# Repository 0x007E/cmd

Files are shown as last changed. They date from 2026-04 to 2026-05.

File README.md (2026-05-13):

  

# `CMD` - Color Matrix Display

The `CMD` is a board with a matrix of [APA102](#additional-information) or any other `SPI` controllable `RGB-LED`. The board itself can be driven with a voltage from `3V3-5V` and controlled over the [APA102 driver library](https://github.com/0x007E/drivers-led-apa102).

| Experience  | Level |
|:---|:---:|
| Soldering | ?% |

# Downloads

| Type | File | Description |
|:---:|:---:|:---|
| Schematic | [pdf](https://github.com/0x007E/cmd/releases/latest/download/schematic.pdf) / [cadlab](https://cadlab.io/project/30127/main/files) | Schematic files |
| Board | [pdf](https://github.com/0x007E/cmd/releases/latest/download/pcb.pdf) / [cadlab](https://cadlab.io/project/30127/main/files) | Board file |
| Drill | [pdf](https://github.com/0x007E/cmd/releases/latest/download/drill.pdf) | Drill file |
| PCB | [zip](https://github.com/0x007E/cmd/releases/latest/download/kicad.zip) / [tar](https://github.com/0x007E/cmd/releases/latest/download/kicad.tar.gz) | KiCAD/Gerber/BoM/Drill files |
| Mechanical | [zip](https://github.com/0x007E/cmd/releases/latest/download/freecad.zip) / [tar](https://github.com/0x007E/cmd/releases/latest/download/freecad.tar.gz) | FreeCAD/Housing and exported step/stl files |

# Hardware

The pcb is created with `KiCAD`, the housing with `FreeCAD`. All files are built with `github actions` so that they are ready for a production environment.

## PCB

The circuit board is populated on both sides (Top, Bottom). The best way for soldering the `SMD` components is within a vapor phase soldering system and for the `THT` components with a standard soldering system.

### Top Layer

Top Layer

### Bottom Layer

Bottom Layer

## Mechanical

The housing has a tolerance of `0.2mm` on each side of the case. So the pcb should fit perfectly in the housing. The tolerance can be modified with `FreeCAD` in the `Parameter` Spreadsheet.

### Assembled

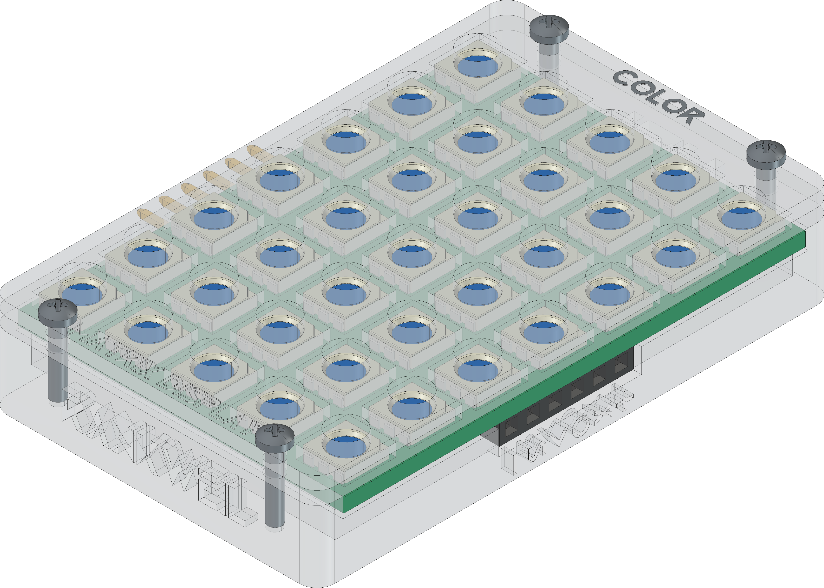
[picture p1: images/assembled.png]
Assembled


### Exploded

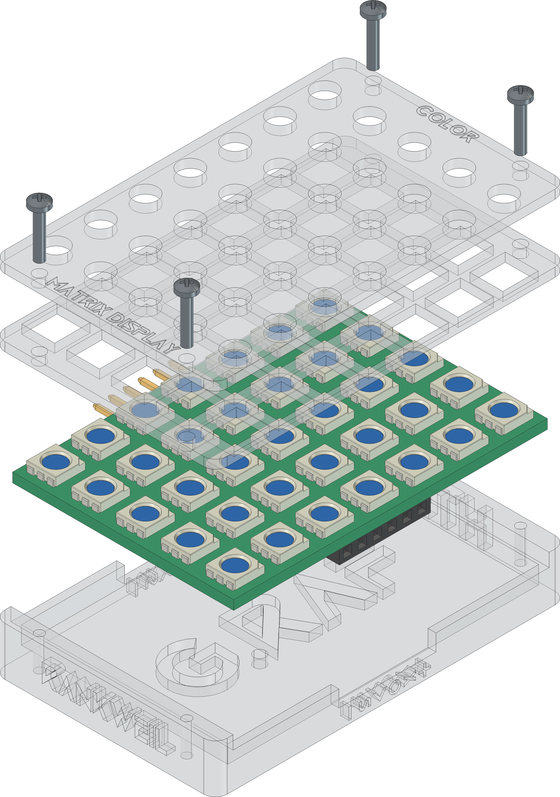
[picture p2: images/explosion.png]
Exploded


# Additional Information

| Type | Link | Description |
|:---:|:---:|:---|
| APA102 | [pdf](https://cdn.sparkfun.com/datasheets/Components/LED/APA102C.pdf) | RGB Full Color LED |
| T3A33BRG | [pdf](https://mm.digikey.com/Volume0/opasdata/d220001/medias/docus/6794/3147_T3A33BRG-H9C0002X1U1930.pdf) | Harvatek Surface Mount PLCC IC+RGB LEDs Data Sheet |

---

R. GAECHTER

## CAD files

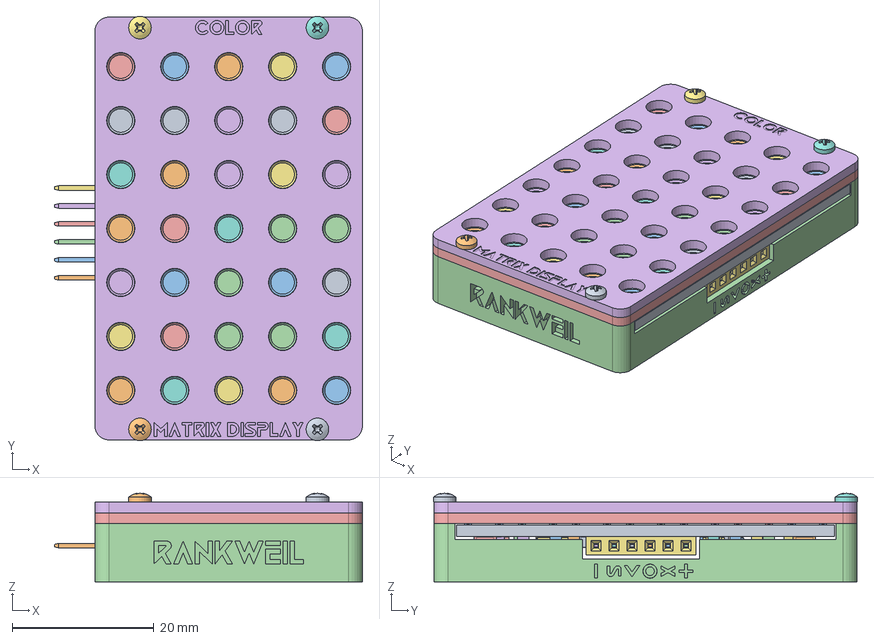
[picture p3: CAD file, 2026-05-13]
mechanical/housing.FCStd
43.5 x 59.9 x 12.5 mm
Pcb_372d
D4_LED_RGB_5050_6_c8d679b3cf96
D12_LED_RGB_5050_6_0d78efd88531
D25_LED_RGB_5050_6_8dd86f10e033
D30_LED_RGB_5050_6_70bff24c3fa8
D5_LED_RGB_5050_6_883a80191dc6
D21_LED_RGB_5050_6_71d8c5f033c3
D18_LED_RGB_5050_6_ae8a0c82b528
D2_LED_RGB_5050_6_2c67bf760a38
D15_LED_RGB_5050_6_4aecfc53b693
D29_LED_RGB_5050_6_020e96eb8e85
D27_LED_RGB_5050_6_e6c08294998b
D13_LED_RGB_5050_6_5207545b7e46
D31_LED_RGB_5050_6_452964f9abc9
D6_LED_RGB_5050_6_48a015607da9
D14_LED_RGB_5050_6_ef4cea893bd8
D33_LED_RGB_5050_6_c87c4f9d566a
D7_LED_RGB_5050_6_5112adf0dffb
D26_LED_RGB_5050_6_b665db2f56eb
D20_LED_RGB_5050_6_2f6135911f3c
D11_LED_RGB_5050_6_c472883db714
D17_LED_RGB_5050_6_168fb854f30b
D24_LED_RGB_5050_6_1e367285d20e
D34_LED_RGB_5050_6_b5d780624194
D9_LED_RGB_5050_6_f686bf059c19
D10_LED_RGB_5050_6_bb3e8f39ce7c
D35_LED_RGB_5050_6_0f7e728d19b2
D32_LED_RGB_5050_6_4ba10b18be2a
D1_LED_RGB_5050_6_5a15a87712d0
D16_LED_RGB_5050_6_1ee0b67086f2
D22_LED_RGB_5050_6_0bfcbbb63ad0
D3_LED_RGB_5050_6_05fda6bf319f
D23_LED_RGB_5050_6_11d82703a68e
D28_LED_RGB_5050_6_e8c2b79452b4
D8_LED_RGB_5050_6_dbcfe5009d1e
D19_LED_RGB_5050_6_2dd7d80de35c
C21_C_1206_3216Metric_becf7b863a9e
R1_R_1206_3216Metric_6b22a116e9fa
C23_C_1206_3216Metric_05f489a1e841
C14_C_1206_3216Metric_c8187b273cda
C4_C_1206_3216Metric_850ed94551e8
C29_C_1206_3216Metric_fef34f46e5df
C24_C_1206_3216Metric_ec1bf5d8af19
C27_C_1206_3216Metric_744eb0be306a
C5_C_1206_3216Metric_9dc838c1d108
C11_C_1206_3216Metric_8e8377dae1bc
C37_CP_EIA_6032_28_Kemet_C_833059fcf426
C6_C_1206_3216Metric_46004fc4bd7c
C31_C_1206_3216Metric_2338b7c74ba9
C13_C_1206_3216Metric_6a7aced0fd8a
C32_C_1206_3216Metric_04f152fb05e5
C33_C_1206_3216Metric_2cd0b1d29f67
C20_C_1206_3216Metric_8fa1f32aacef
C35_C_1206_3216Metric_f7d56debbe7d
M20-7910642R
M20-7910642R001
M20-7910642R002
M20-7910642R003
M20-7910642R004
M20-7910642R005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

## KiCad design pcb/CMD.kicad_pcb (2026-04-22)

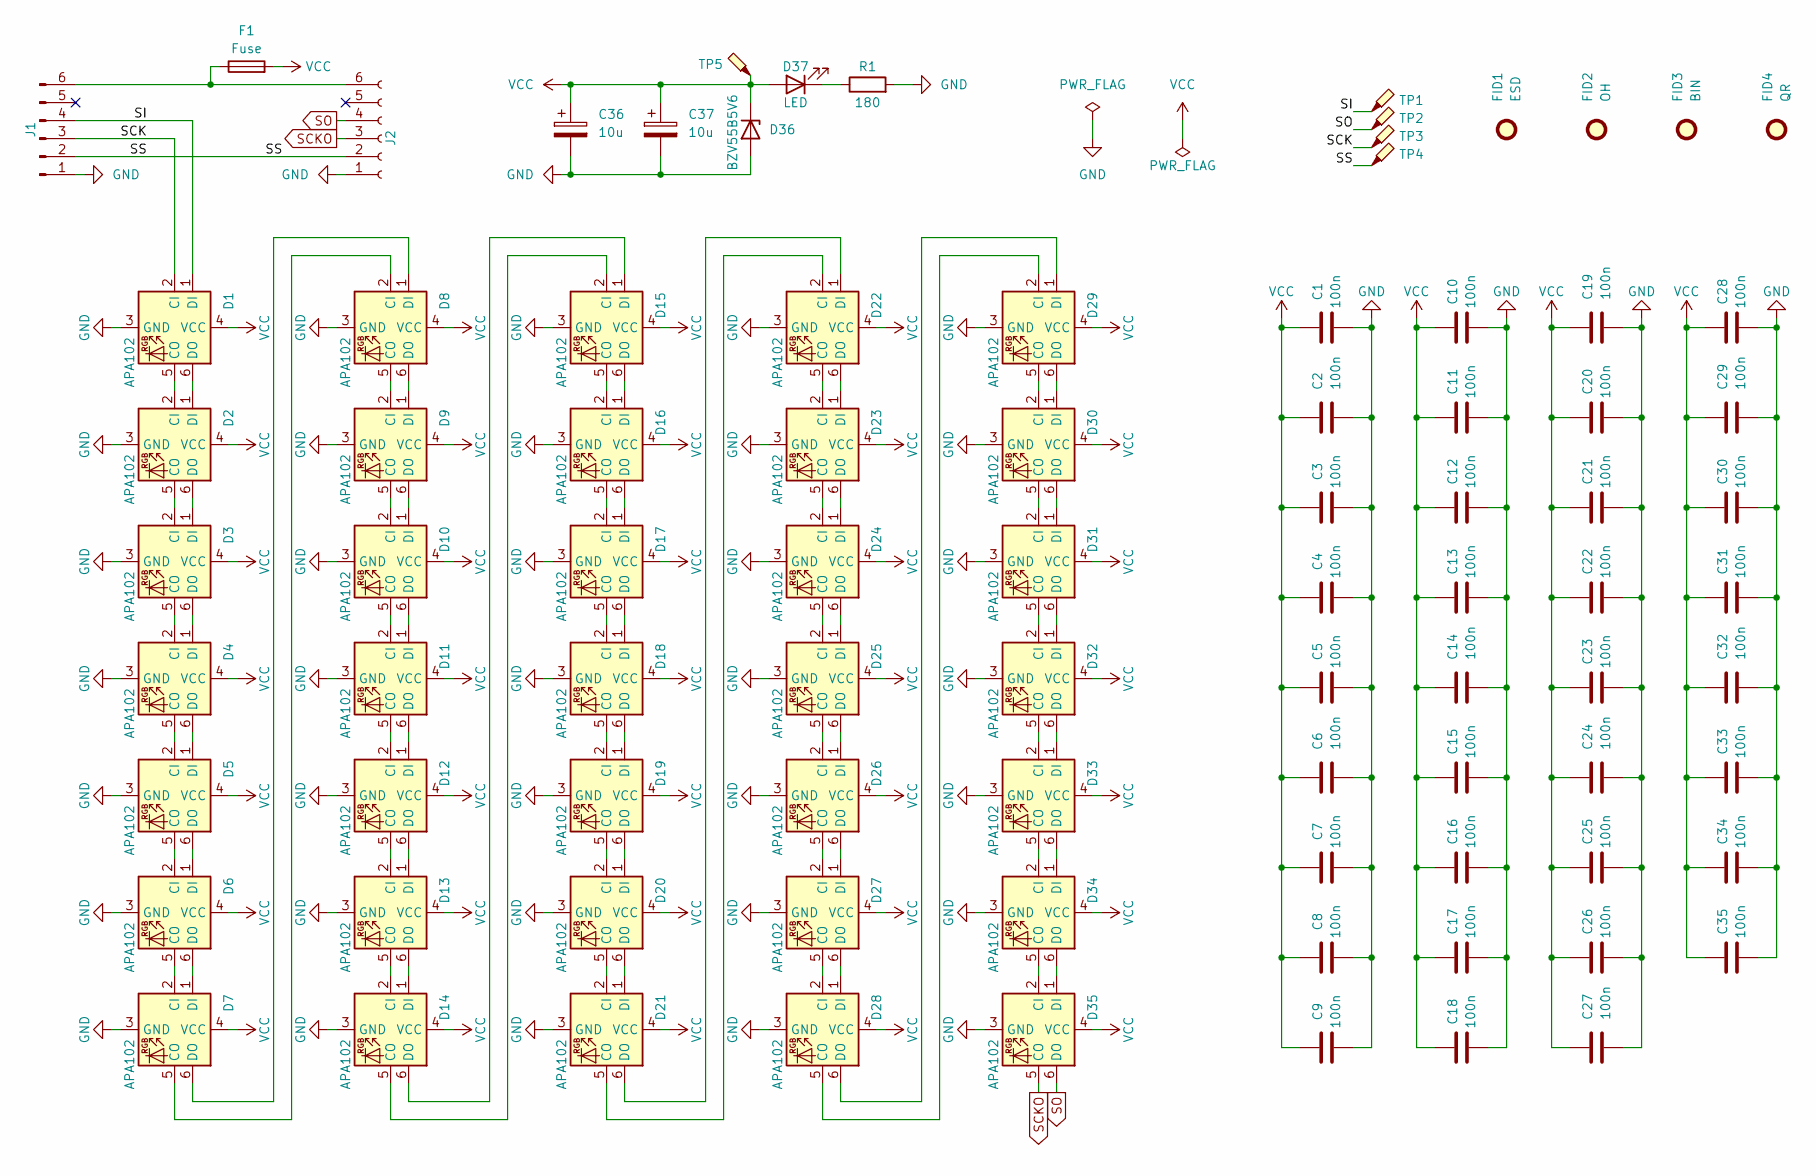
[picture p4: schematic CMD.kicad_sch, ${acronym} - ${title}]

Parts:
C1, C2, C3, C4, C5, C6, C7, C8, C9, C10, C11, C12, C13, C14, C15, C16, C17, C18, C19, C20, C21, C22, C23, C24, C25, C26, C27, C28, C29, C30, C31, C32, C33, C34, C35: 100n; C_1206_3216Metric
C36, C37: 10u; CP_EIA-6032-28_Kemet-C
D1, D2, D3, D4, D5, D6, D7, D8, D9, D10, D11, D12, D13, D14, D15, D16, D17, D18, D19, D20, D21, D22, D23, D24, D25, D26, D27, D28, D29, D30, D31, D32, D33, D34, D35: APA102; LED_RGB_5050-6
D36: BZV55B5V6; D_MiniMELF
D37: LED; LED_1206_3216Metric
F1: Fuse; Fuse_1206_3216Metric
FID1: ESD; ESD-Logo_6.6x6mm_SilkScreen
FID2: OH; OSHW-Logo_5.7x6mm_SilkScreen
FID3: BIN; WEEE-Logo_4.2x6mm_SilkScreen
FID4: QR; QR_0x007e_very_small
J1: Conn_01x06_Pin; HARWIN_M20-8890645_Pin_Header
J2: Conn_01x06_Socket; HARWIN_M20-7910642R_Pin_Socket
R1: 180; R_1206_3216Metric
TP1, TP2, TP3, TP4, TP5: TestPoint_Probe; TestPoint_Pad_D1.0mm

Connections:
/SCK: D1.2 (CI), J1.3, TP3.1
/SI: D1.1 (DI), J1.4, TP1.1
/SS: J1.2, J2.2, TP4.1
GND: C1.1, C2.2, C3.1, C4.1, C5.1, C6.2, C7.1, C8.1, C9.1, C10.1, C11.1, C12.1, C13.1, C14.2, C15.1, C16.1, C17.1, C18.1, C19.2, C20.1, C21.1, C22.1, C23.1, C24.2, C25.1, C26.1, C27.2, C28.1, C29.2, C30.1, C31.1, C32.2, C33.1, C34.1, C35.1, C36.2, C37.2, D1.3 (GND), D2.3 (GND), D3.3 (GND), D4.3 (GND), D5.3 (GND), D6.3 (GND), D7.3 (GND), D8.3 (GND), D9.3 (GND), D10.3 (GND), D11.3 (GND), D12.3 (GND), D13.3 (GND), D14.3 (GND), D15.3 (GND), D16.3 (GND), D17.3 (GND), D18.3 (GND), D19.3 (GND), D20.3 (GND), D21.3 (GND), D22.3 (GND), D23.3 (GND), D24.3 (GND), D25.3 (GND), D26.3 (GND), D27.3 (GND), D28.3 (GND), D29.3 (GND), D30.3 (GND), D31.3 (GND), D32.3 (GND), D33.3 (GND), D34.3 (GND), D35.3 (GND), D36.2 (A), J1.1, J2.1, R1.2
unnamed: D1.5 (CO), D2.2 (CI)
unnamed: D1.6 (DO), D2.1 (DI)
unnamed: D2.5 (CO), D3.2 (CI)
unnamed: D2.6 (DO), D3.1 (DI)
unnamed: D3.5 (CO), D4.2 (CI)
unnamed: D3.6 (DO), D4.1 (DI)
unnamed: D4.5 (CO), D5.2 (CI)
unnamed: D4.6 (DO), D5.1 (DI)
unnamed: D5.5 (CO), D6.2 (CI)
unnamed: D5.6 (DO), D6.1 (DI)
unnamed: D6.5 (CO), D7.2 (CI)
unnamed: D6.6 (DO), D7.1 (DI)
unnamed: D7.5 (CO), D8.2 (CI)
unnamed: D7.6 (DO), D8.1 (DI)
unnamed: D8.5 (CO), D9.2 (CI)
unnamed: D8.6 (DO), D9.1 (DI)
unnamed: D9.5 (CO), D10.2 (CI)
unnamed: D10.5 (CO), D11.2 (CI)
unnamed: D9.6 (DO), D10.1 (DI)
unnamed: D10.6 (DO), D11.1 (DI)
unnamed: D11.5 (CO), D12.2 (CI)
unnamed: D11.6 (DO), D12.1 (DI)
unnamed: D12.5 (CO), D13.2 (CI)
unnamed: D12.6 (DO), D13.1 (DI)
unnamed: D13.5 (CO), D14.2 (CI)
unnamed: D13.6 (DO), D14.1 (DI)
unnamed: D14.5 (CO), D15.2 (CI)
unnamed: D14.6 (DO), D15.1 (DI)
unnamed: D15.5 (CO), D16.2 (CI)
unnamed: D15.6 (DO), D16.1 (DI)
unnamed: D16.5 (CO), D17.2 (CI)
unnamed: D16.6 (DO), D17.1 (DI)
unnamed: D17.5 (CO), D18.2 (CI)
unnamed: D17.6 (DO), D18.1 (DI)
unnamed: D18.5 (CO), D19.2 (CI)
unnamed: D18.6 (DO), D19.1 (DI)
unnamed: D19.5 (CO), D20.2 (CI)
unnamed: D19.6 (DO), D20.1 (DI)
unnamed: D20.5 (CO), D21.2 (CI)
unnamed: D20.6 (DO), D21.1 (DI)
unnamed: D21.5 (CO), D22.2 (CI)
unnamed: D21.6 (DO), D22.1 (DI)
unnamed: D22.5 (CO), D23.2 (CI)
unnamed: D22.6 (DO), D23.1 (DI)
unnamed: D23.5 (CO), D24.2 (CI)
unnamed: D23.6 (DO), D24.1 (DI)
unnamed: D24.5 (CO), D25.2 (CI)
unnamed: D24.6 (DO), D25.1 (DI)
unnamed: D25.5 (CO), D26.2 (CI)
unnamed: D25.6 (DO), D26.1 (DI)
unnamed: D26.5 (CO), D27.2 (CI)
unnamed: D26.6 (DO), D27.1 (DI)
unnamed: D27.5 (CO), D28.2 (CI)
unnamed: D27.6 (DO), D28.1 (DI)
unnamed: D28.5 (CO), D29.2 (CI)
unnamed: D28.6 (DO), D29.1 (DI)
unnamed: D29.5 (CO), D30.2 (CI)
unnamed: D29.6 (DO), D30.1 (DI)
unnamed: D30.5 (CO), D31.2 (CI)
unnamed: D30.6 (DO), D31.1 (DI)
unnamed: D31.5 (CO), D32.2 (CI)
unnamed: D31.6 (DO), D32.1 (DI)
unnamed: D32.5 (CO), D33.2 (CI)
unnamed: D32.6 (DO), D33.1 (DI)
unnamed: D33.5 (CO), D34.2 (CI)
unnamed: D33.6 (DO), D34.1 (DI)
unnamed: D34.5 (CO), D35.2 (CI)
unnamed: D34.6 (DO), D35.1 (DI)
unnamed: D37.1 (K), R1.1
unnamed: F1.1, J1.6, J2.6
SCKO: D35.5 (CO), J2.3
SO: D35.6 (DO), J2.4, TP2.1
VCC: C1.2, C2.1, C3.2, C4.2, C5.2, C6.1, C7.2, C8.2, C9.2, C10.2, C11.2, C12.2, C13.2, C14.1, C15.2, C16.2, C17.2, C18.2, C19.1, C20.2, C21.2, C22.2, C23.2, C24.1, C25.2, C26.2, C27.1, C28.2, C29.1, C30.2, C31.2, C32.1, C33.2, C34.2, C35.2, C36.1, C37.1, D1.4 (VCC), D2.4 (VCC), D3.4 (VCC), D4.4 (VCC), D5.4 (VCC), D6.4 (VCC), D7.4 (VCC), D8.4 (VCC), D9.4 (VCC), D10.4 (VCC), D11.4 (VCC), D12.4 (VCC), D13.4 (VCC), D14.4 (VCC), D15.4 (VCC), D16.4 (VCC), D17.4 (VCC), D18.4 (VCC), D19.4 (VCC), D20.4 (VCC), D21.4 (VCC), D22.4 (VCC), D23.4 (VCC), D24.4 (VCC), D25.4 (VCC), D26.4 (VCC), D27.4 (VCC), D28.4 (VCC), D29.4 (VCC), D30.4 (VCC), D31.4 (VCC), D32.4 (VCC), D33.4 (VCC), D34.4 (VCC), D35.4 (VCC), D36.1 (K), D37.2 (A), F1.2, TP5.1

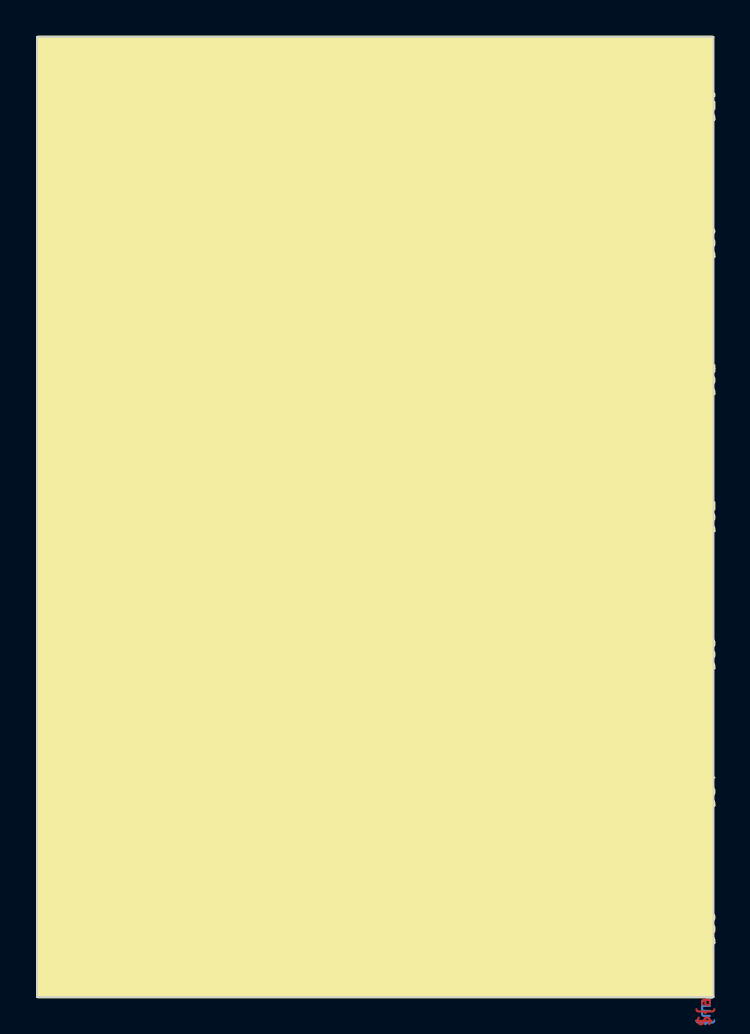
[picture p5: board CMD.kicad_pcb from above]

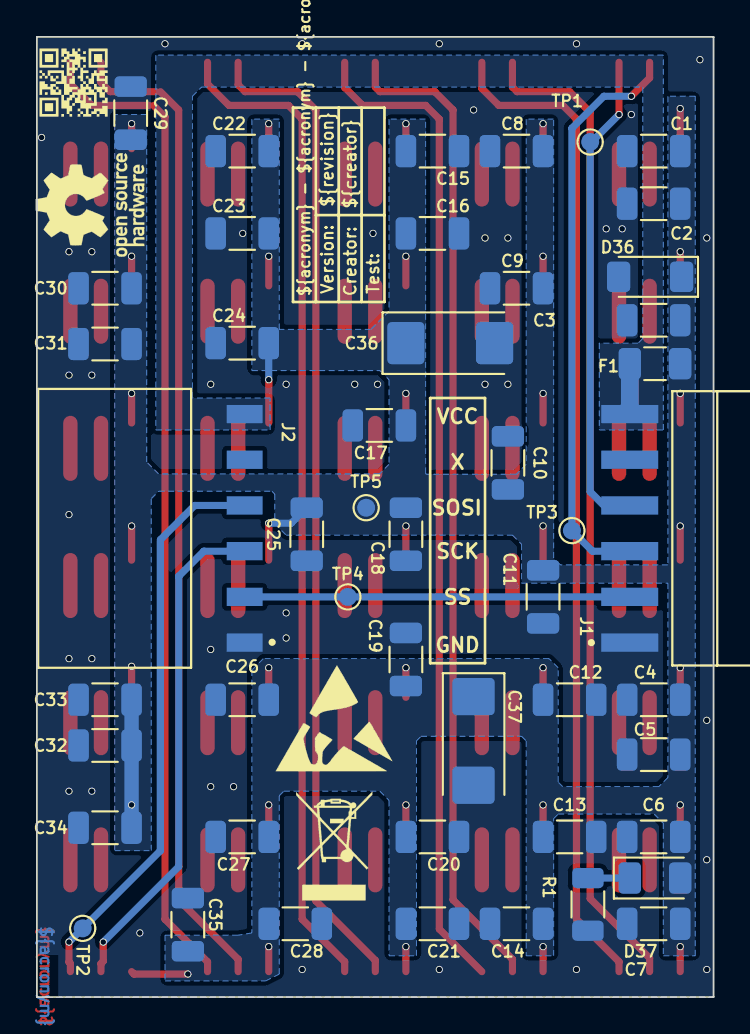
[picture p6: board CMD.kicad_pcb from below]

Board: 2 copper layers, 37.6 x 53.3 mm, 87 parts (52 on the bottom side), 77 nets.

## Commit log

2026-03-03 Add pcb layout
    [CMD.kicad_pcb, CMD.kicad_sch]
2026-04-08 Arrange fabrication layers
    [CMD.kicad_pcb]
2026-04-08 Add reference designator to fabrication layer
    [CMD.kicad_pcb]
2026-04-08 Add fabrication identifier
    [CMD.kicad_pcb]
2026-04-08 Remove led values from fabrication layer
    [CMD.kicad_pcb]
2026-04-13 Fix led position and add extended dimensioning
    [CMD.kicad_pcb]
2026-04-13 Add mechanical parts
    [housing.FCStd]
2026-04-14 Lower pcb width
    [CMD.kicad_pcb]
2026-04-14 Shrink housing width
    [housing.FCStd]
2026-04-22 Adapt vendor(id)
    [CMD.kicad_pcb, CMD.kicad_sch]
2026-05-13 Add assembly explosion
    [housing.FCStd]

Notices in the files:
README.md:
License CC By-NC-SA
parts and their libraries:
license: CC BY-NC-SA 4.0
